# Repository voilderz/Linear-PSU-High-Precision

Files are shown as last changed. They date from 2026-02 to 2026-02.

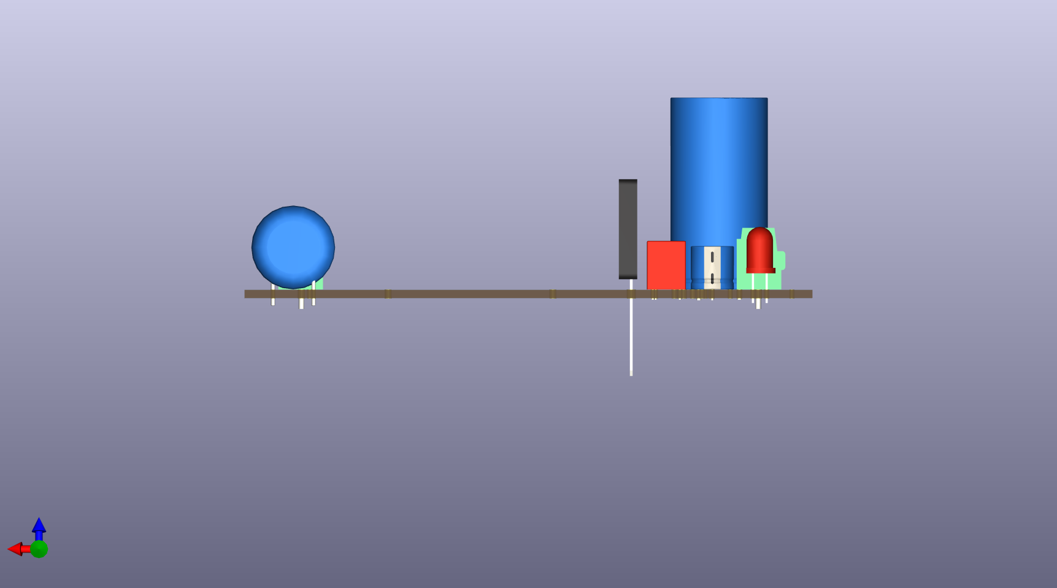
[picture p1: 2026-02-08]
Images/Back.png

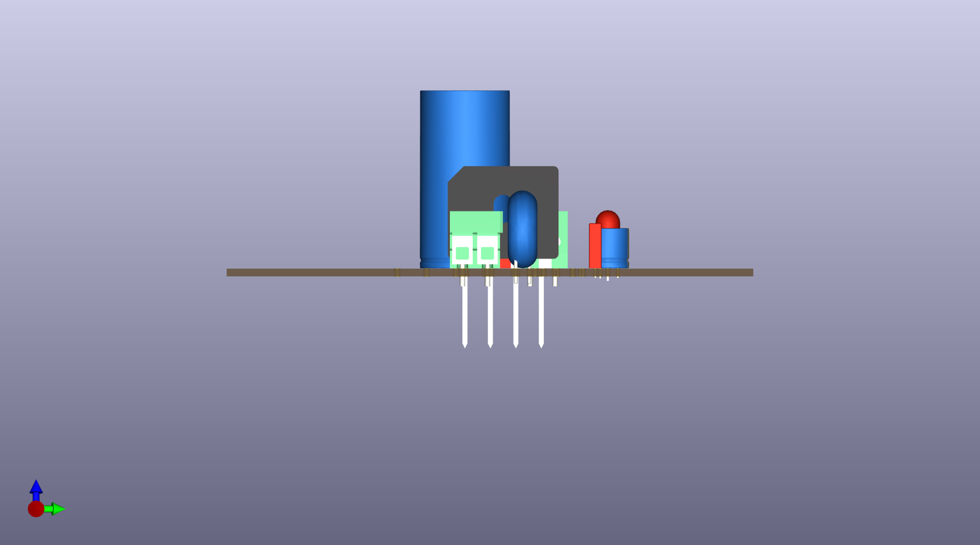
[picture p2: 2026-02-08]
Images/Right.png

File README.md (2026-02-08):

# Linear-PSU-High-Precision

This project is an industrial-grade power module designed for high-stability electronic systems requiring precision voltage regulation. The design focuses on ultra-low noise energy delivery, thermal stability, and electrical safety.

---

### Changelog - v1.1 (February 2026)

* **Safety Seal:** Integrated **B72314S2271K101** MOV to the mains input for enhanced surge and transient protection.
* **Isolation Discipline:** Established a complete physical isolation barrier between AC and DC zones to eliminate arcing risks.
* **Visual Identity:** Branded the PCB with **VOI** logo and v1.1 versioning on the silkscreen layer for professional traceability.

---

## Overview
This module converts $230\text{V}$ AC grid voltage into highly regulated, low-ripple $5\text{V}$ and $15\text{V}$ DC outputs. It is engineered to serve as a reliable power platform for sensitive sensor networks and control units.

## Technical Specifications
| Parameter | Value |
| :--- | :--- |
| **Input Voltage** | $230\text{V}$ AC ($50\text{/60Hz}$) |
| **Output Voltage** | $5\text{V}$ DC Regulated |
| **Continuous Current** | $1.916\text{ A}$ Max |
| **Precision** | $0.1\%$ Tolerance (Voltage Reference Rail) |
| **Efficiency** | Up to $95\%$ (Traco Power Integration) |

## Key Engineering Features
* **High-Voltage Isolation:** A **$2.0\text{ mm}$ clearance** is maintained between primary (AC) and secondary (DC) stages, fully compliant with **IPC-2221** safety standards.
* **Thermal Management:** Power traces are widened to **$1.5\text{ mm}$ ($35\mu\text{m}$ copper)** and reinforced with "Teardrops" at pad junctions to ensure mechanical and thermal integrity under high current loads.
* **Precision Components:** Implementation of **YR1B1K0CC** series $0.1\%$ tolerance metal film resistors to minimize thermal drift and maintain long-term voltage accuracy.
* **EMI Shielding:** Integrated **Copper Pours** (Ground Planes) across all layers to suppress electromagnetic interference and ensure signal integrity.

## Bill of Materials (BOM)
| Reference | Component | MPN | Impact |
| :--- | :--- | :--- | :--- |
| **U1** | Regulator | TSR 3-2450 | High-efficiency switching regulation. |
| **TR1** | Transformer | ASL171112 | Certified primary-side galvanic isolation. |
| **R1** | Precision Resistor | MFR-25FTE52-1K | $0.1\%$ stability for feedback loops. |
| **C1** | Capacitor | B41858C5688M000 | 6800uF Low-ESR ripple suppression. |

> For the comprehensive industrial-grade BOM, see: [/BOM/BOM_Linear_PSU_Extended.csv](./BOM/BOM_Linear_PSU_Extended.csv)

## Project Structure
* **/Hardware:** KiCad schematic and PCB layout source files.
* **/Production:** Production-ready **Gerber** and **Drill** files (ZIP archive).
* **/Docs:** Full schematic PDF and critical component datasheets.
* **/Images:** 3D renders and technical captures.

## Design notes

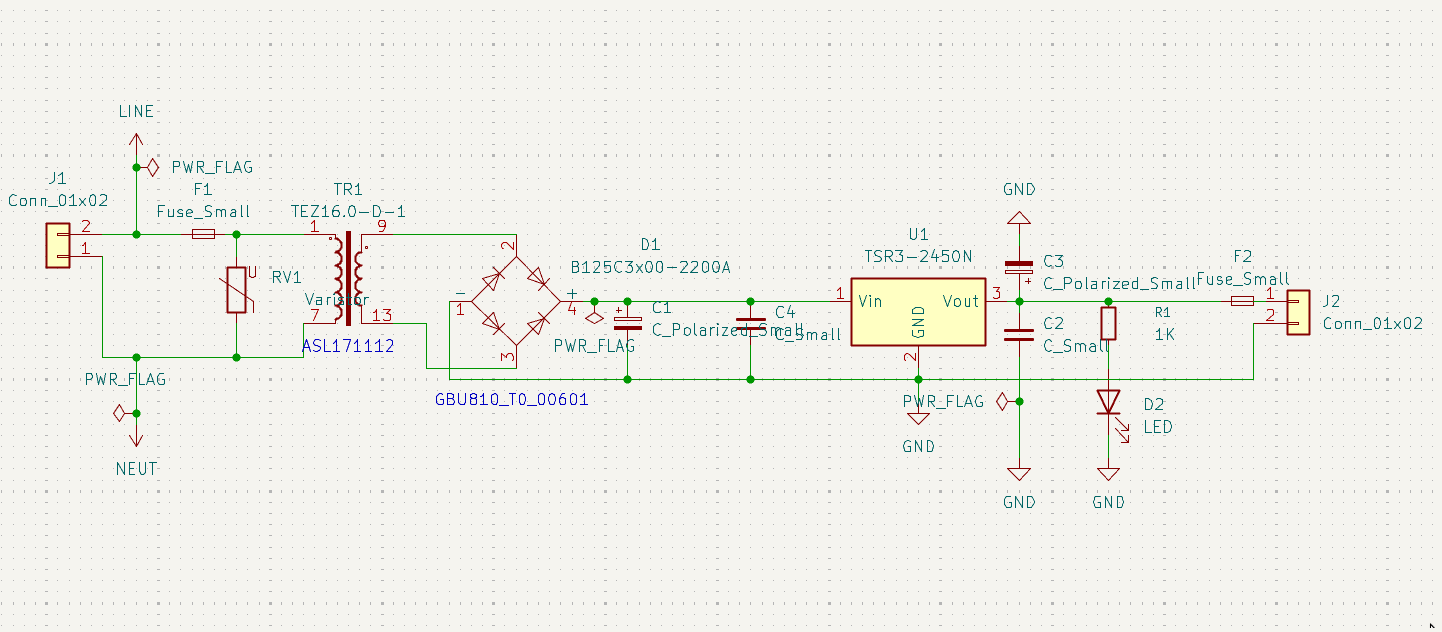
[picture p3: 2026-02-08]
Images/Schematic_Capture.png

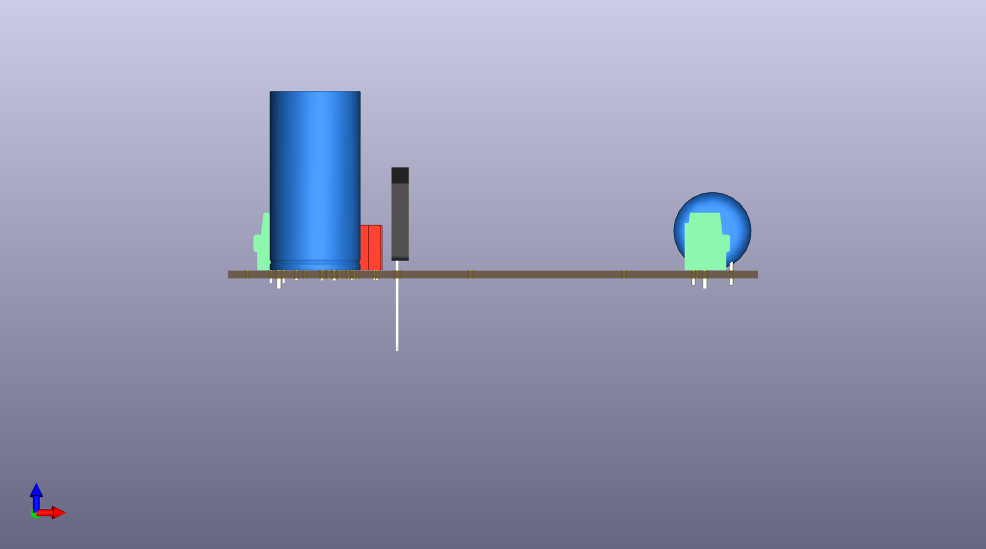
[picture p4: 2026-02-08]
Images/Front.png

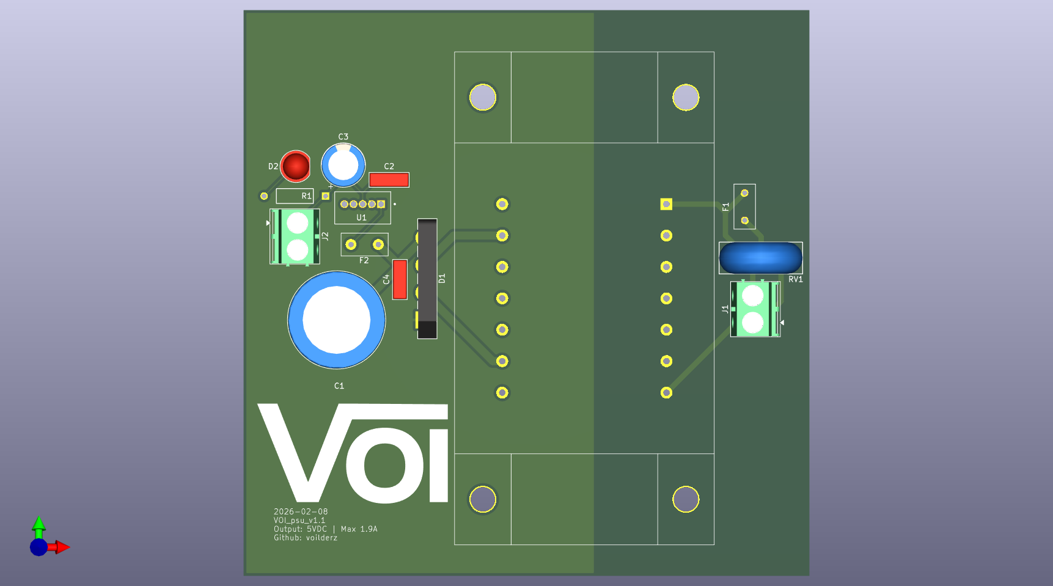
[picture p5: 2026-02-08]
Images/Top.png

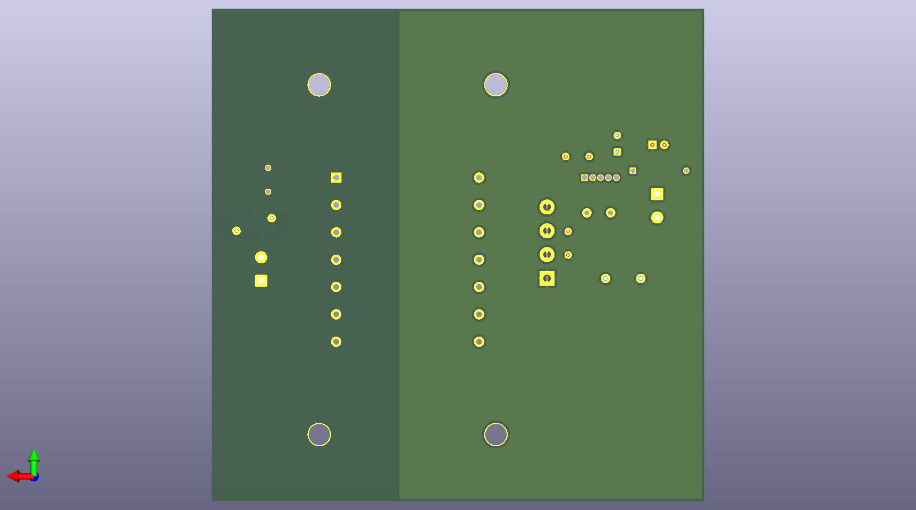
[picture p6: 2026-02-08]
Images/Bottom.png

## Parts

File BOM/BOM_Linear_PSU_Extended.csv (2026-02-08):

Reference | Component | MPN | Extended Description
TR1 | Transformer | ASL171112 | 230V AC Primary Step-Down Transformer: High galvanic isolation with low electromagnetic interference (EMI) profile for grid safety.
D1 | Diode Bridge | GBU810_T0_00601 | Full-Wave Bridge Rectifier: High-current capacity stage designed for efficient AC to DC energy conversion with minimal voltage drop.
C1 | Capacitor (Electrolytic) | B41858C5688M000 | Bulk Filtration: 6800uF 25V Low-ESR (Equivalent Series Resistance) Aluminum Electrolytic Capacitor for maximum ripple voltage suppression.
C2, C4 | Capacitor (Film) | MKS2C031001A00KSSD | Transient Decoupling: Metallized Polyester (PET) Film Capacitors for high-frequency noise filtering and input/output stability.
C3 | Capacitor (Polymer) | A7C5KN227M1EAAS029 | Precision Smoothing: High-stability Conductive Polymer Aluminum Solid Capacitor for low-noise output rail regulation.
LED1 | LED | 3R4HD-7-TB | Status Indicator: High-efficiency Red LED (660 nm) for real-time power-on diagnostic and visual verification.
F1 | Fuse (Primary) | 0697H0250 | Primary Overcurrent Protection: 250mA Slow-Blow (Time-Delay) subminiature fuse for AC grid surge protection.
F2 | Fuse (Secondary) | 80812500000 | Secondary Rail Protection: 2.5A Fast-Acting subminiature radial leaded fuse for load-side short-circuit mitigation.
U1 | Regulator | TSR 3-2450 | High-Efficiency Switching Regulator: Traco Power non-isolated step-down converter with up to 95% peak efficiency for thermal management.
R1 | Resistor (1k Ohm) | MFR-25FTE52-1K | Precision Current Limiting: 1k Ohm High-Precision metal film resistor with 1% tolerance for optimized LED longevity and stability.
J1, J2 | Connector | KF129V-5.08-2P | Heavy-Duty Power Interface: 5.08mm pitch screw terminal blocks for secure and robust field wire connections.
RV1 | Varistor | B72314S2271K101 | 275VAC Metal Oxide Varistor (MOV) for input surge and transient protection

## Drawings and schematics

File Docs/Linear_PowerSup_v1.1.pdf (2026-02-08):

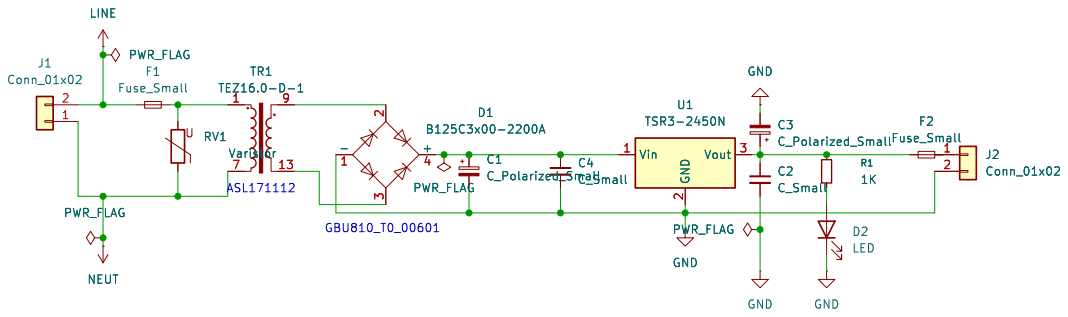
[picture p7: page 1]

Id: 1/1 Title: File: Linear_PowerSup_v1.1.kicad_sch Sheet: /

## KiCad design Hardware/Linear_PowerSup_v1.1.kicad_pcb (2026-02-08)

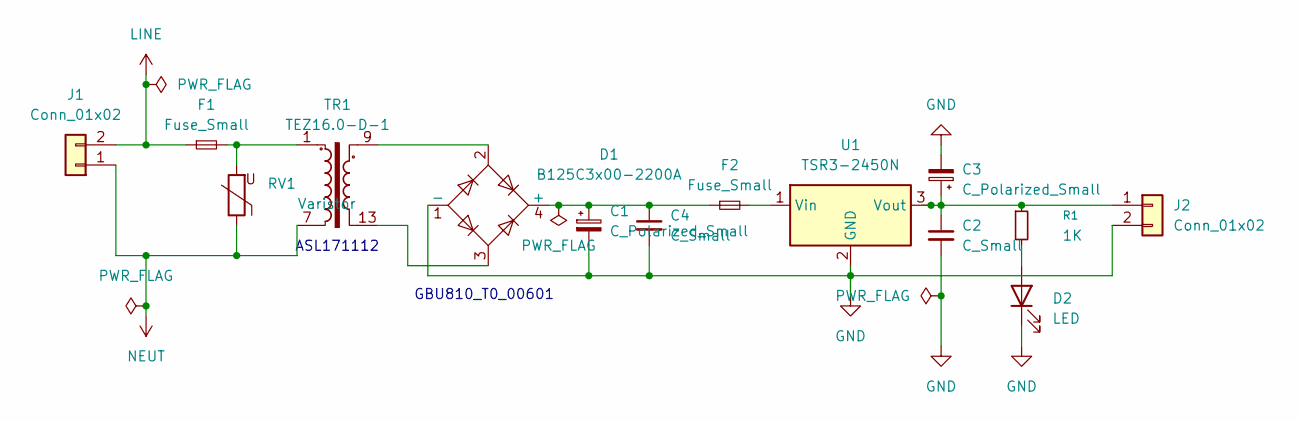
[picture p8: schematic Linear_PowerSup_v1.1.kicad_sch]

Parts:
C1: C_Polarized_Small; C_Radial_D18.0mm_H35.5mm_P7.50mm
C2, C4: C_Small; C_Rect_L7.2mm_W2.5mm_P5.00mm_FKS2_FKP2_MKS2_MKP2
C3: C_Polarized_Small; CP_Radial_D8.0mm_P3.50mm
D1: B125C3x00-2200A; Diode_Bridge_Vishay_GBU
D2: LED; LED_D5.0mm
F1: Fuse_Small; FUSRR508W60L835T400H810
F2: Fuse_Small; Fuse_Littelfuse_395Series
J1, J2: Conn_01x02; TerminalBlock_Phoenix_PT-1,5-2-5.0-H_1x02_P5.00mm_Horizontal
R1: 1K; RES_TYCO_YR1_TYC
RV1: Varistor; RV_Disc_D15.5mm_W5.9mm_P7.5mm
TR1: TEZ16.0-D-1; ASL171112
U1: TSR3-2450N; CONV_TSR_3-2450

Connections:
GND: C1.2, C2.2, C3.2, C4.2, D1.1 (-), D2.1 (K), J2.2, U1.2 (GND)
LINE: F1.1, J1.2
NEUT: J1.1, RV1.1, TR1.7
unnamed: C1.1, C4.1, D1.4 (+), F2.1
unnamed: D1.2, TR1.9
unnamed: D1.3, TR1.13
unnamed: D2.2 (A), R1.2
unnamed: F1.2, RV1.2, TR1.1
unnamed: C2.1, C3.1, J2.1, R1.1, U1.3 (Vout)
unnamed: F2.2, U1.1 (Vin)

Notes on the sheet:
GBU810_T0_00601
ASL171112

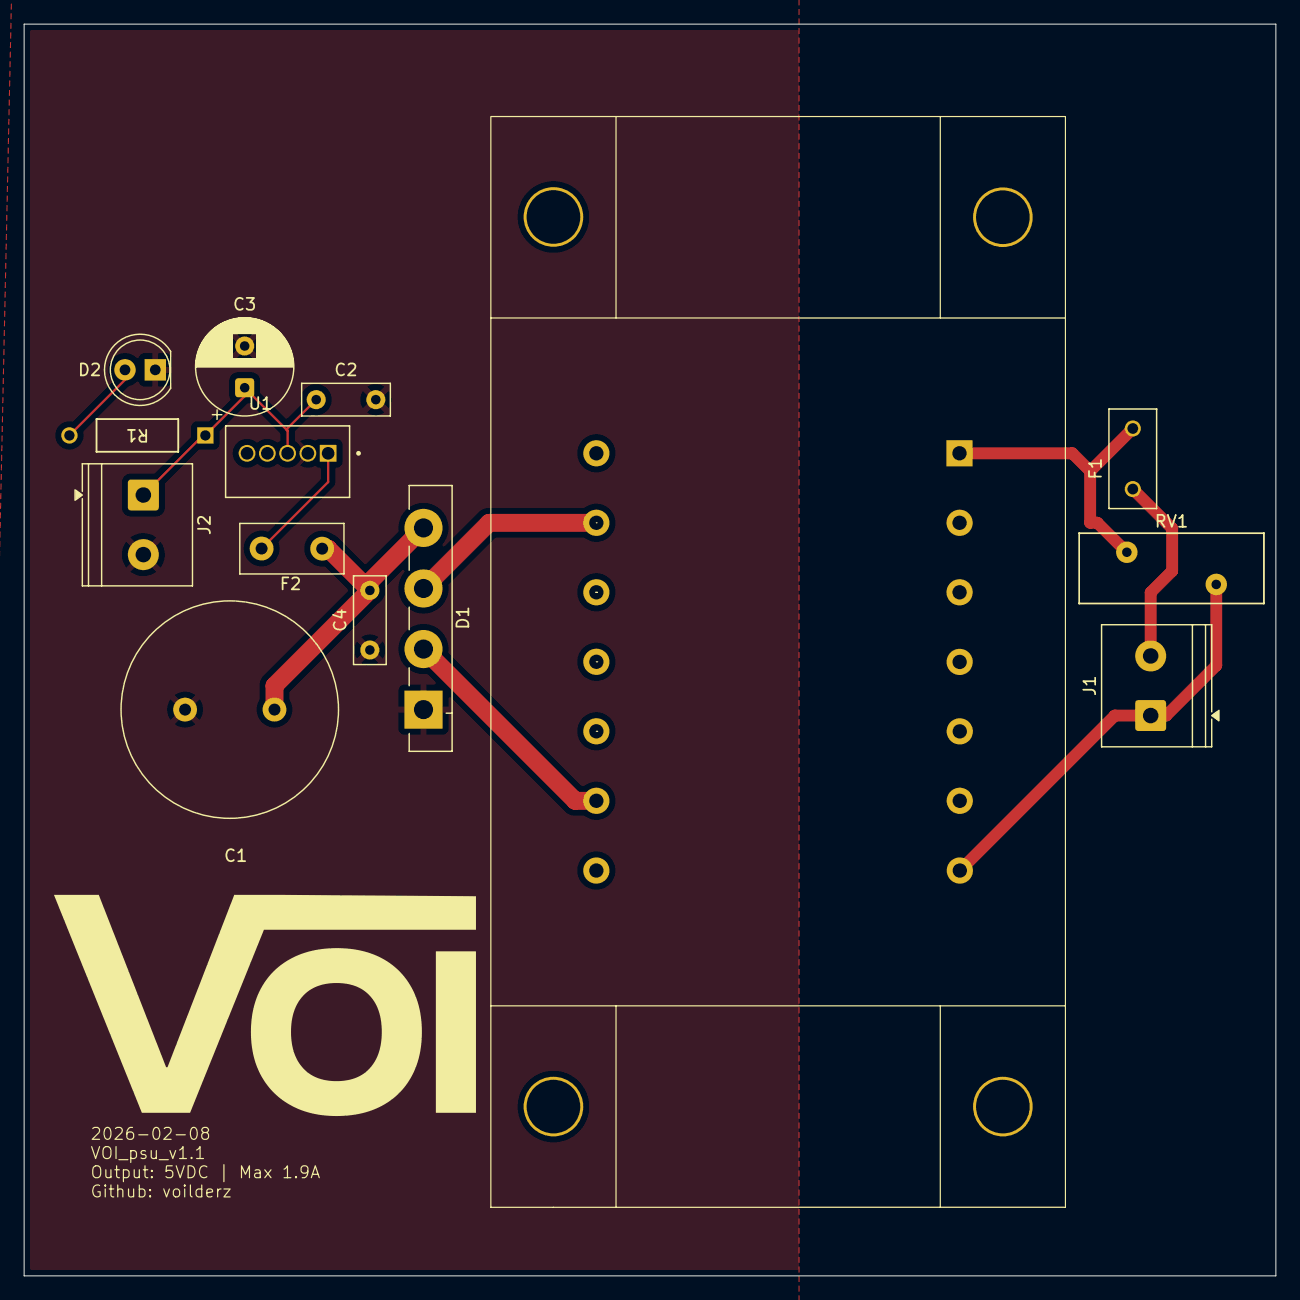
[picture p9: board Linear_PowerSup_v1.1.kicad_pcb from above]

Board: 2 copper layers, 105.0 x 105.0 mm, 14 parts (0 on the bottom side), 10 nets.

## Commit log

2026-02-05 Enhance README with detailed project information
    Expanded project description and added technical specifications, key features, and bill of materials.
2026-02-08 v1.1 Update
    [Linear_PowerSup_v1.1.kicad_pcb, Linear_PowerSup_v1.1.kicad_sch]
